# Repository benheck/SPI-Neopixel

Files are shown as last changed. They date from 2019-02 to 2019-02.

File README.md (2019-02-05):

# SPI-Neopixel
Circuit to convert 800kHz SPI bus mode 1 into WS2812 "Neopixel" pulse width data

/CS (chip select active low) allows you to have other things on the same SPI bus as this converter.

Tested in breadboard form to be working. Ordered PCB's using this board file from OSHpark. Will update when that has been tested.

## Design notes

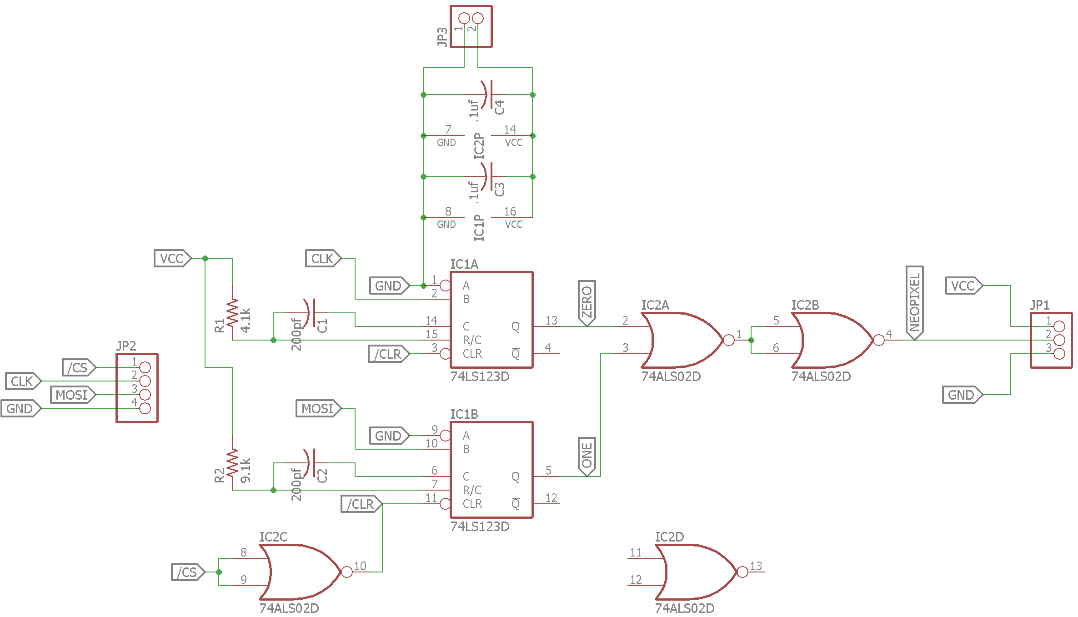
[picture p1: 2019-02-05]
schematic_image.png

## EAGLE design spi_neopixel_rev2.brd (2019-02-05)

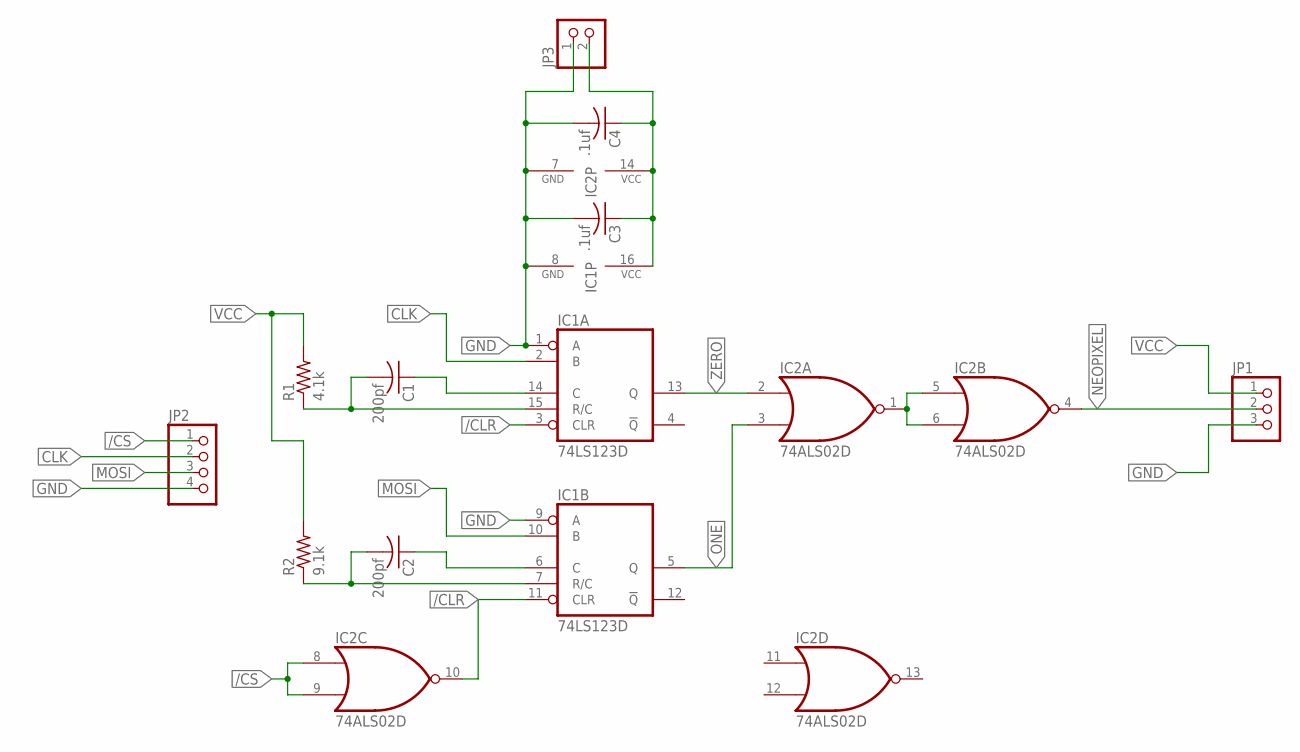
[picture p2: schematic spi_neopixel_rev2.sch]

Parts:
C1, C2: 200pf; C0805
C3, C4: .1uf; C0805
IC1: 74LS123D; SO16
IC2: 74ALS02D; SO14
JP1: PINHD-1X3; 1X03
JP2: PINHD-1X4; 1X04
JP3: PINHD-1X2; 1X02
R1: 4.1k; M0805
R2: 9.1k; M0805

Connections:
/CLR: IC1.3 (CLR), IC1.11 (CLR), IC2.10 (O)
/CS: IC2.8 (I0), IC2.9 (I1), JP2.1
CLK: IC1.2 (B), JP2.2
GND: C3.2, C4.2, IC1.1 (A), IC1.8 (GND), IC1.9 (A), IC2.7 (GND), JP1.3, JP2.4, JP3.1
MOSI: IC1.10 (B), JP2.3
unnamed: IC2.1 (O), IC2.5 (I0), IC2.6 (I1)
unnamed: C1.2, IC1.15 (R/C), R1.1
unnamed: C2.2, IC1.7 (R/C), R2.1
unnamed: C1.1, IC1.14 (C)
unnamed: C2.1, IC1.6 (C)
NEOPIXEL: IC2.4 (O), JP1.2
ONE: IC1.5 (Q), IC2.3 (I1)
VCC: C3.1, C4.1, IC1.16 (VCC), IC2.14 (VCC), JP1.1, JP3.2, R1.2, R2.2
ZERO: IC1.13 (Q), IC2.2 (I0)

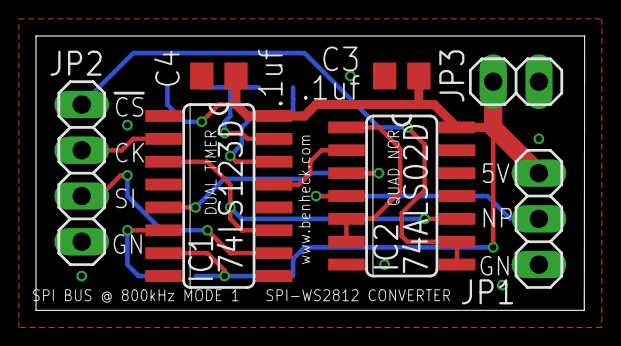
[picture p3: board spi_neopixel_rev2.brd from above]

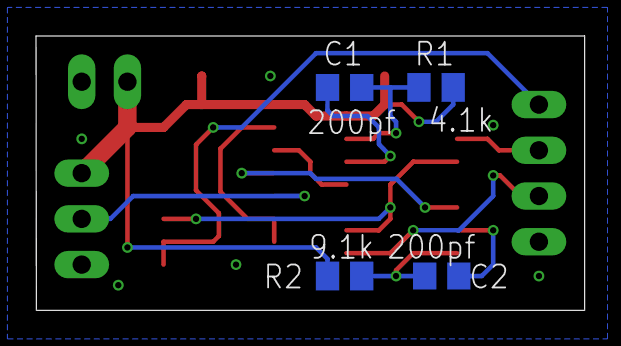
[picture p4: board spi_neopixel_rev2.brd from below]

Board: 2 copper layers, 30.5 x 15.2 mm, 11 parts (4 on the bottom side), 14 nets.

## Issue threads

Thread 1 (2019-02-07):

Schematic with only 74xx02 will not work

Raffi611, 2019-02-07:
The schematic that is given will not work, if two '1' are send in succsesion the monostable that should
generate the700ns will not trigger on the second '1'. Also if MOSI is held high while idle, then if the fist bit is an '1' it will fail to trigger as well.
